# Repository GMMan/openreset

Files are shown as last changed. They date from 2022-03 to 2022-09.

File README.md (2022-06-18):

OpenReset Project
=================

This project is designed to allow you to easily reset your card with a
standalone device. No need to connect to a computer to use (in fact you can't
read the card from a computer using this device).

Supported cards:
- Vital Bracelet Dim
- Vital Bracelet Memory (VBM)
- TamaSma Card
- PreData Memory (for Heart Cure Watch, unreleased as of writing)

DIY hardware
------------

It is easy to build your own OpenReset from loose parts.

### Bill of materials

To build your own OpenReset, you will need the following:

- 1x Raspberry Pi Pico
- 1x microSD card breakout board (suggested model TBD)
- 1x Red LED
- 1x Resistor (for current limiting the LED; please calculate the value based
  on your LED's datasheet, but in general a 330Ω resistor will work)
- 1x Toggle switch or button if your breakout board does not have card detect
  broken out
- 1x Breadboard (optional)
- Hookup wires

### Hardware connection

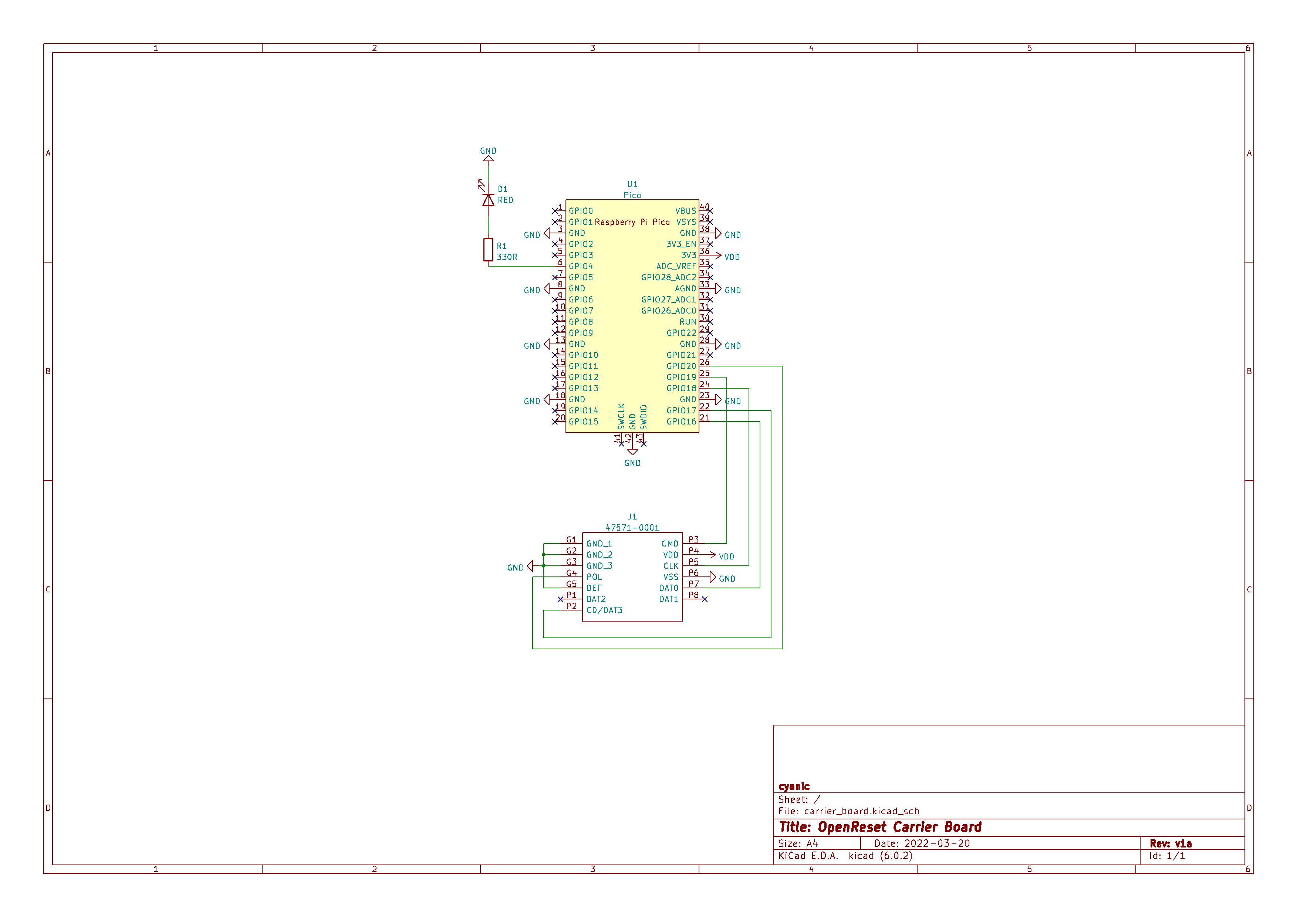
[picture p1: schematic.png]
Schematic


1. Connect the `3V3` pin on the Pico to your positive power rail and any `GND`
   pin to your ground rail.
2. Connect the microSD card breakout to the Pico as follows:
   - Pico pin 21 to `DAT0` or `MISO`
   - Pico pin 22 to `DAT3` or `CS`
   - Pico pin 24 to `CLK` or `CLK`
   - Pico pin 25 to `CMD` or `MOSI`
   - Pico pin 26 to card detect. Note, if your breakout board does not have a
     card detect pin, you can connect a toggle switch or button to pin 26, and
     connect the other side to ground.
3. Connect the red LED such that the anode end has the Pico's pin 6 upstream.
   Connect a resistor before or after the LED, and connect the loose end of the
   LED or resistor to ground.

Carrier board
-------------

Alternatively, you can have a carrier board fabbed and solder the Pi Pico to it
along with a few other components.

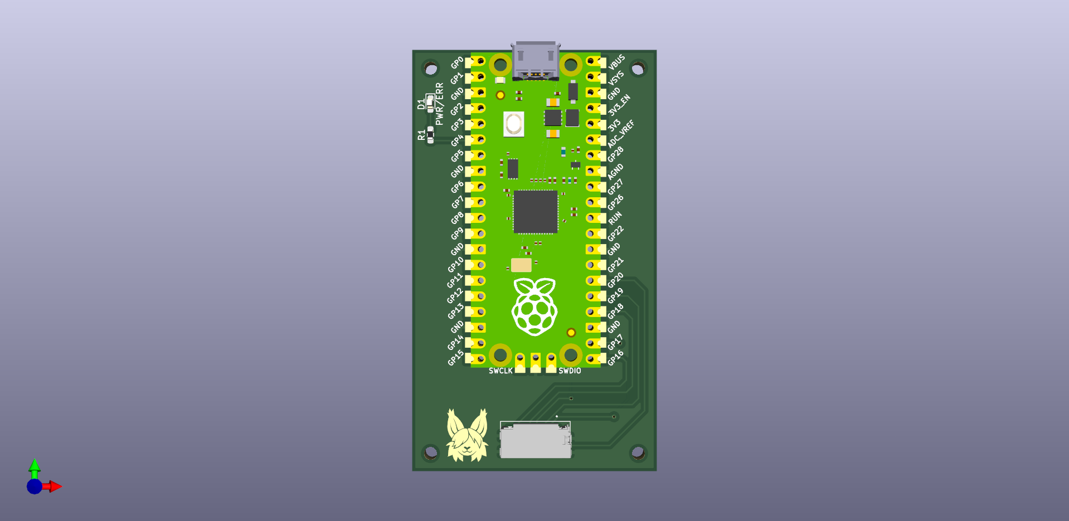
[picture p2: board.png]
Board


Board design files are in the [carrier_board](carrier_board) directory. Gerbers
are available in the [carrier_board/gerber](carrier_board/gerber) directory,
and are available as a [ZIP file](carrier_board/gerber/openreset_carrier_board_v1c.zip).

### Bill of materials

- 1x Raspberry Pi Pico (`U1`) ([Official resellers](https://www.raspberrypi.com/products/raspberry-pi-pico/#find-reseller))
- 1x Molex 0475710001 push-pull microSD card connector (`J1`) ([Digikey](https://www.digikey.ca/en/products/detail/molex/0475710001/3262277))
- 1x 0603 Red LED (`D1`)
- 1x 0603 Resistor (`R1`) (for current limiting the LED; please calculate the
  value based on your LED's datasheet, but in general a 330Ω resistor will work)

Software setup
--------------

1. Install MicroPython on to your Pi Pico
   - Download a recent build from [here](https://micropython.org/download/rp2-pico/)
   - Hold the `BOOTSEL` button on your Pico, then plug the Pico into your
     computer while still holding the button. You can release the button
     once the Pico shows up on your computer as a USB drive.
   - Drag the .uf2 firmware you have downloaded to the USB drive, and the
     Pico will install the firmware and reboot
2. Upload the code in the [firmware](firmware) directory to the Pico
   - I use [Thonny](https://thonny.org/). After you install it, open it up
     and click the button at the bottom right of the screen. Select
     `MicroPython (Raspberry Pi Pico)`.
   - Open up each file in the firmware directory, and select `File ->
     Save copy...` from the menu strip. Click `Raspbery Pi Pico` when asked
     where to save to. Type in the name of the file in the `File name` box,
     and click `OK`.
3. Replug the Pico and verify the code is installed
   - The red LED should be lit

Usage
-----

The board is easy to use. All you have to do is insert your card and the device
will automatically perform the erase. The red LED will always be on to indicate
power, and the green LED on the Pi Pico will light up when the erase is in
progress. After the erase is completed, the green LED will extinguish. If there
is an error, the red LED will blink off a number of times to indicate the error.

- 1 time: wrong card type, check you are using the correct card
- 2 times: wrong flash chip; if you are sure your card is genuine, file an
  issue in this repo
- 3 times: card is not responding as expected

There are messages printed to UART if you need more info on troubleshooting.
I suggest loading the code up in Thonny and checking the shell for the
messages.

**Warning:** TamaSma Card locking area is embedded in the card header. By
nature of SPI NOR flash, changing this data will involve erasing the sector,
so there is a risk of breaking the data if the connection is bad. Therefore,
be careful when plugging in a TamaSma Card to plug it in firmly.

If your are using a DIY build and your microSD breakout board does not have a
card detect pin, then you can use the switch/button alternative. Flip the
switch or hold the button after you have inserted a card. The process will
complete and the red LED will flash if there are errors. If you are using a
button, make sure to hold the button until the error has finished blinking, if
applicable. Flip the switch again or release the button before inserting the
next card.

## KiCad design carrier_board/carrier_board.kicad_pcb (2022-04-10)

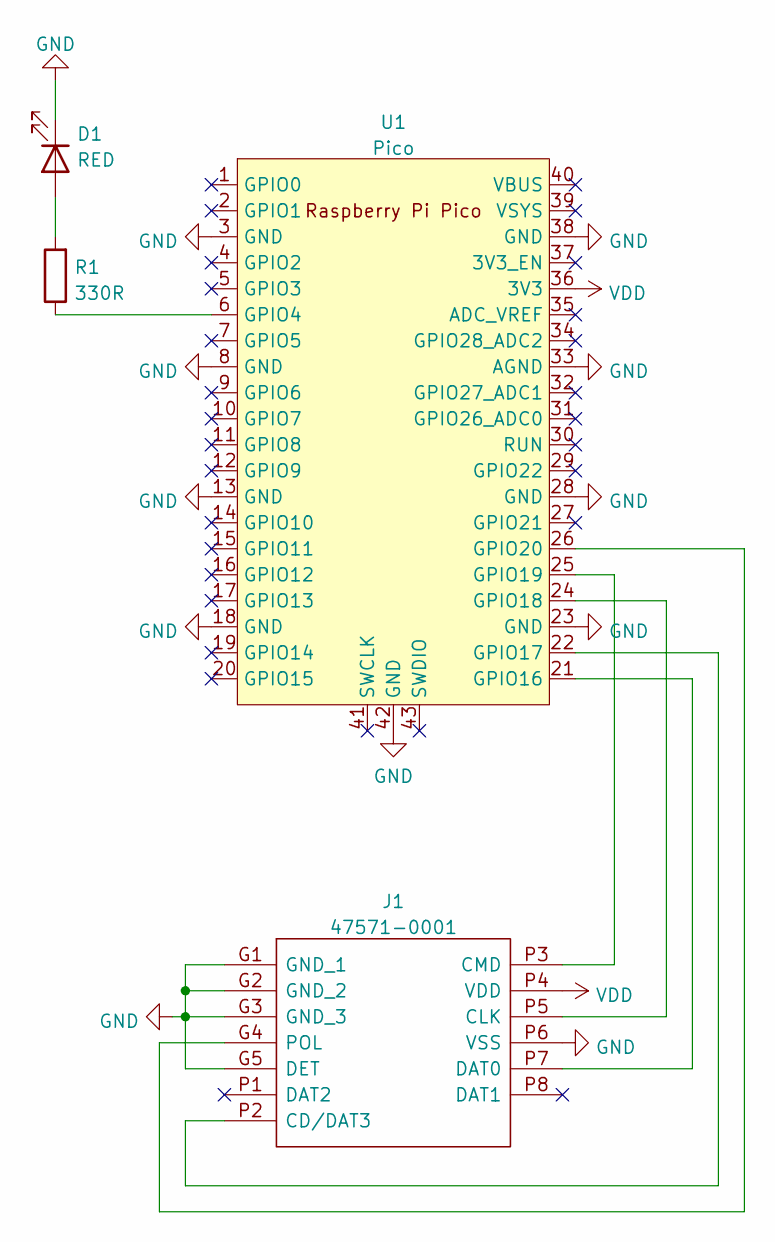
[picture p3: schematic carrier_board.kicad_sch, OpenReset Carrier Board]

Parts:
D1: RED; LED_0603_1608Metric_Pad1.05x0.95mm_HandSolder
J1: 47571-0001; 475710001; Mouser Part Number 538-47571-0001
R1: 330R; R_0603_1608Metric_Pad0.98x0.95mm_HandSolder
U1: Pico; RPi_Pico_SMD_TH

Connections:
GND: D1.1 (K), J1.G1 (GND_1), J1.G2 (GND_2), J1.G3 (GND_3), J1.G5 (DET), J1.P6 (VSS), U1.3 (GND), U1.8 (GND), U1.13 (GND), U1.18 (GND), U1.23 (GND), U1.28 (GND), U1.33 (AGND), U1.38 (GND), U1.42 (GND)
unnamed: J1.G4 (POL), U1.26 (GPIO20)
unnamed: J1.P2 (CD/DAT3), U1.22 (GPIO17)
unnamed: J1.P3 (CMD), U1.25 (GPIO19)
unnamed: J1.P5 (CLK), U1.24 (GPIO18)
unnamed: J1.P7 (DAT0), U1.21 (GPIO16)
unnamed: D1.2 (A), R1.2
unnamed: R1.1, U1.6 (GPIO4)
VDD: J1.P4 (VDD), U1.36 (3V3)

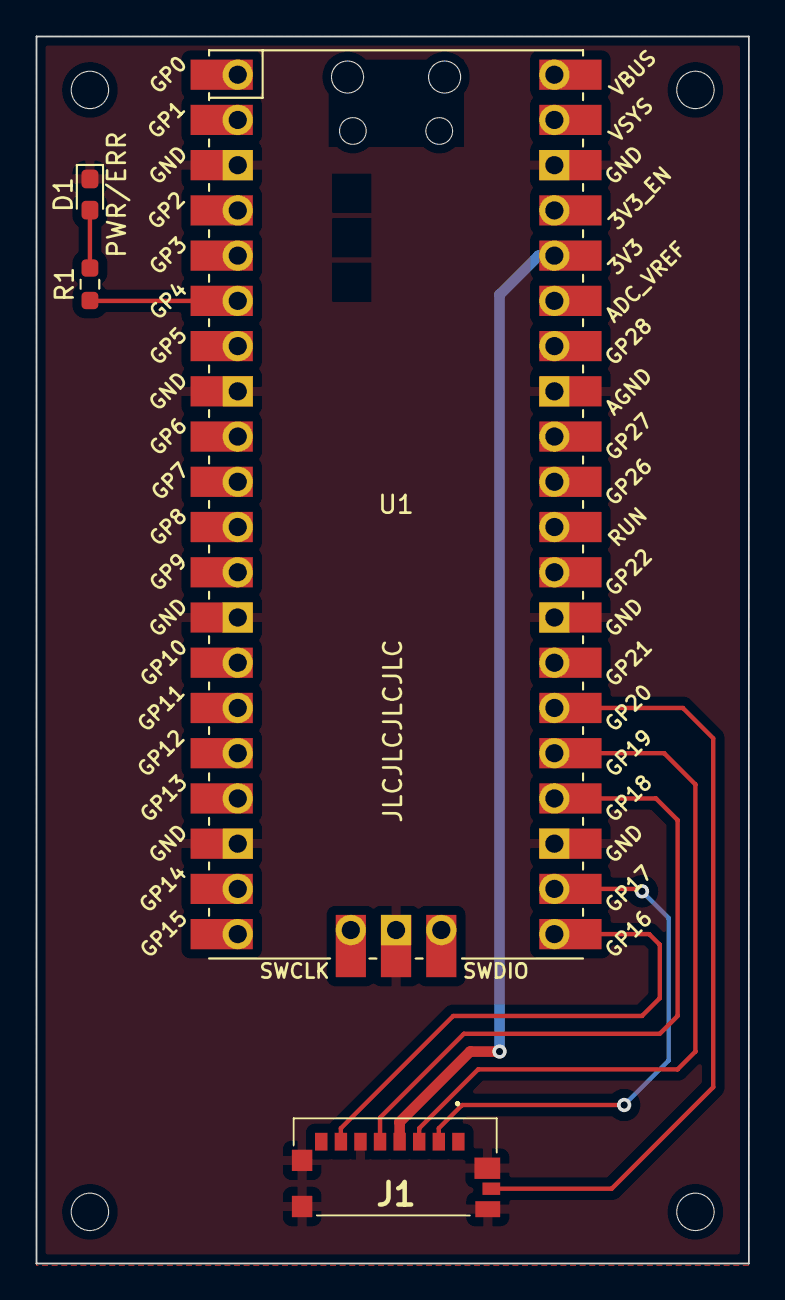
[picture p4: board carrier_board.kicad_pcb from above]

Board: 2 copper layers, 40.0 x 68.9 mm, 4 parts (0 on the bottom side), 9 nets.

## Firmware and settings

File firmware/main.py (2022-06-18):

# SPDX-License-Identifier: GPL-3.0-or-later
#
# This file is part of OpenReset.
#
# Copyright (C) 2022  cyanic
#
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
import machine
import time
import common

from resetters import *

# Hardware definitions ========================================================

# LEDs
led_green = machine.Pin(25, machine.Pin.OUT)
led_red = machine.Pin(4, machine.Pin.OUT)

# Card detect
card_detect = machine.Pin(20, machine.Pin.IN, machine.Pin.PULL_UP)

# SPI
spi_sck = machine.Pin(18)
spi_mosi = machine.Pin(19)
spi_miso = machine.Pin(16)
spi_cs = machine.Pin(17, machine.Pin.OUT)

spi = machine.SPI(0, baudrate=2_000_000, sck=spi_sck, mosi=spi_mosi,
                  miso=spi_miso)

resetters = [DimResetter, TamaSmaCardResetter, PreDataMemoryResetter]

def blink_err(times):
    # Blink off
    for _ in range(times):
        led_red.value(0)
        time.sleep_ms(common.LED_BLINK_TIME_MS)
        led_red.value(1)
        time.sleep_ms(common.LED_BLINK_TIME_MS)

# Main loop ===================================================================

# Red LED on by default to indicate power
led_red.value(1)
led_green.value(0)

while True:
    # Wait until card is inserted (reads low)
    while card_detect.value() != 0:
        time.sleep_ms(50)

    # Light LED to indicate we are running
    led_green.value(1)
    print('Card inserted')
    # Wait a bit in case card is still being inserted
    time.sleep_ms(200)

    ret = common.ERR_WRONG_CARD

    # Iterate the resetters, and if detect OK, perform reset
    for resetter in resetters:
        print('Checking for {}'.format(resetter.__name__))
        ret = resetter.detect(spi, spi_cs)
        if ret == common.ERR_OK:
            print('Detected by {}'.format(resetter.__name__))
            resetter_inst = resetter(spi, spi_cs)
            ret = resetter_inst.do_reset()
            break

    # Done, extinguish LED
    led_green.value(0)

    if ret == common.ERR_WRONG_CARD:
        print('Card type unrecognized')

    if ret != common.ERR_OK:
        # Blink error until card removed
        while card_detect.value() == 0:
            blink_err(ret)
            time.sleep_ms(1000)
    else:
        # Wait until card is removed (reads high)
        while card_detect.value() == 0:
            time.sleep_ms(50)
    print('Card removed')

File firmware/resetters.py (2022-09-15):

# SPDX-License-Identifier: GPL-3.0-or-later
#
# This file is part of OpenReset.
#
# Copyright (C) 2022  cyanic
#
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
from hashlib import sha256
from binascii import hexlify

from md5 import md5
from spi_flash import SPIFlashDriver, MX25LDriver
import common

class DimResetter:
    ID_HASH = b'\xb2\xdc\xb5\x07\x7c\x68\xd2\xd5\x40\xde\x10\x45\x9a\x06\x18\x23\x2a\x21\x17\xd3\x48\xac\x10\xf2\x89\x8f\xb1\x5c\x61\x46\x84\x82'
    FLASH_ID = b'\xc2\x20\x16'  # MX25L3233F
    ERASE_ADDRS = [0x10000, 0x90000, 0xa0000]

    def __init__(self, spi, cs) -> None:
        self.flash = MX25LDriver(spi, cs)

    def do_reset(self):
        print('Starting process')

        # Remove block protection
        sr = self.flash.rdsr()
        cr = self.flash.rdcr()
        # Unset BP0-3
        sr &= 0x40  # Retain QE, ignore WEL and WIP, unset all other bits
        self.flash.wren()
        self.flash.wrsr(sr, cr)
        if not common.wait_write_complete(self.flash, common.WRITE_WAIT_TIMEOUT_MS):
            print('Write timeout when removing write protection')
            return common.ERR_TIMEOUT

        # Erase blocks
        for addr in self.ERASE_ADDRS:
            self.flash.wren()
            self.flash.be(addr)
            if not common.wait_write_complete(self.flash, common.WRITE_WAIT_TIMEOUT_MS):
                print('Write timeout while erasing block address 0x{:06x}'.format(addr))
                return common.ERR_TIMEOUT

        # Reprotect blocks
        sr = self.flash.rdsr()
        cr = self.flash.rdcr()
        # Set BP0-3
        sr |= 0x3c
        self.flash.wren()
        self.flash.wrsr(sr, cr)
        if not common.wait_write_complete(self.flash, common.WRITE_WAIT_TIMEOUT_MS):
            print('Write timeout when setting write protection')
            # Not critical, so we won't return an error

        # Done!
        print('Process complete')
        return common.ERR_OK

    @classmethod
    def detect(cls, spi, cs):
        # Read and verify this is the correct type of card
        flash = MX25LDriver(spi, cs)
        id_data = flash.read(0x10, 0x22)
        hasher = sha256(id_data)
        hash_bytes = hasher.digest()
        if hash_bytes != cls.ID_HASH:
            # print('Card type check failed. Read data:')
            # print(hexlify(id_data))
            return common.ERR_WRONG_CARD

        # Check flash ID
        flash_id = flash.rdid()
        if flash_id != cls.FLASH_ID:
            # print('Flash ID didn\'t match. Read ID:')
            # print(hexlify(flash_id))
            return common.ERR_WRONG_FLASH_ID

        return common.ERR_OK


class TamaSmaCardResetter:
    ID_HASH = b'\x12\xef\xbb\x0a\xd7\x93\xd7\xd0\xd2\x16\xda\xdb\x30\x14\x66\xa2\xc3\xd0\xb1\xb1\x77\x7c\xcd\x9b\xfe\x4d\x29\xd2\xc7\x7a\x7f\xba'

    def __init__(self, spi, cs) -> None:
        self.flash = SPIFlashDriver(spi, cs)

    def do_reset(self):
        print('Starting process')

        # Read header
        header = bytearray(self.flash.read(0x0, 0x100))
        # Clear locks
        header[0x04:0x10] = b'\0' * 12
        # Recalculate checksum
        hash = md5(header[0x00:0x40])
        header[0x40:0x50] = hash.to_bytes(16, 'little')
        # Clear rest of the page with zeroes
        header[0x50:0x100] = b'\0' * 0xb0

        # Erase sector
        self.flash.wren()
        self.flash.se(0x0)
        if not common.wait_write_complete(self.flash, common.WRITE_WAIT_TIMEOUT_MS):
            print('Write timeout while erasing header sector')
            return common.ERR_TIMEOUT

        # Program header page
        self.flash.wren()
        self.flash.pp(0x0, header)
        if not common.wait_write_complete(self.flash, common.WRITE_WAIT_TIMEOUT_MS):
            print('Write timeout while programming header')
            return common.ERR_TIMEOUT

        # Clear entire page with zeroes and program to rest of sector
        header = bytearray(0x100)
        for i in range(0x100, 0x1000, 0x100):
            self.flash.wren()
            self.flash.pp(i, header)
            if not common.wait_write_complete(self.flash, common.WRITE_WAIT_TIMEOUT_MS):
                print('Write timeout while programming page 0x{:06x}'.format(i))
                return common.ERR_TIMEOUT

        # Done!
        print('Process complete')
        return common.ERR_OK

    @classmethod
    def detect(cls, spi, cs):
        # Read and verify this is the correct type of card
        flash = SPIFlashDriver(spi, cs)
        id_data = flash.read(0x10, 0x22)
        hasher = sha256(id_data)
        hash_bytes = hasher.digest()
        if hash_bytes != cls.ID_HASH:
            # print('Card type check failed. Read data:')
            # print(hexlify(id_data))
            return common.ERR_WRONG_CARD

        return common.ERR_OK


class PreDataMemoryResetter:
    ID_HASH = b'\xda\x15\x3a\x43\x7d\x99\xe0\x78\x91\xfc\xc7\x73\x46\xd6\x7a\x0c\xde\x9c\x75\xa1\x44\x80\x28\x37\x01\xc8\xe2\x8b\x51\xa6\x0b\x74'
    FLASH_ID = b'\xc8\x40\x14'  # GD25Q80E
    ERASE_ADDRS = [0xfd000, 0xfe000, 0xff000]

    def __init__(self, spi, cs) -> None:
        self.flash = SPIFlashDriver(spi, cs)

    def do_reset(self):
        print('Starting process')

        # Clear lock sectors with zeroes
        zeros = bytearray(0x100)
        for i in range(0xfd000, 0x100000, 0x100):
            self.flash.wren()
            self.flash.pp(i, zeros)
            if not common.wait_write_complete(self.flash, common.WRITE_WAIT_TIMEOUT_MS):
                print('Write timeout while programming page 0x{:06x}'.format(i))
                return common.ERR_TIMEOUT

        # Done!
        print('Process complete')
        return common.ERR_OK

    @classmethod
    def detect(cls, spi, cs):
        # Read and verify this is the correct type of card
        flash = SPIFlashDriver(spi, cs)
        id_data = flash.read(0x10, 0x20)
        hasher = sha256(id_data)
        hash_bytes = hasher.digest()
        if hash_bytes != cls.ID_HASH:
            # print('Card type check failed. Read data:')
            # print(hexlify(id_data))
            return common.ERR_WRONG_CARD

        # Check flash ID
        flash_id = flash.rdid()
        if flash_id != cls.FLASH_ID:
            # print('Flash ID didn\'t match. Read ID:')
            # print(hexlify(flash_id))
            return common.ERR_WRONG_FLASH_ID

        return common.ERR_OK

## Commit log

2022-03-20 Change red LED from GP2 to GP4 to free up UART RX
    Also add label to LED on board
    [carrier_board-B_Cu.gbl, carrier_board-B_Mask.gbs, carrier_board-B_Paste.gbp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]
2022-03-21 Fix weird 3v3 routing
    [carrier_board-B_Cu.gbl, carrier_board-B_Mask.gbs, carrier_board-B_Paste.gbp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]
2022-04-10 Thicken power trace
    [carrier_board-B_Cu.gbl, carrier_board-B_Mask.gbs, carrier_board-B_Paste.gbp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]
2022-04-10 Update LED connection instruction
2022-09-15 Update PreData Memory resetter with new info
    [resetters.py]

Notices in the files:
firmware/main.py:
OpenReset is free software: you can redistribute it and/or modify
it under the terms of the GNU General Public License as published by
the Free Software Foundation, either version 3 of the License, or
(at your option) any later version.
